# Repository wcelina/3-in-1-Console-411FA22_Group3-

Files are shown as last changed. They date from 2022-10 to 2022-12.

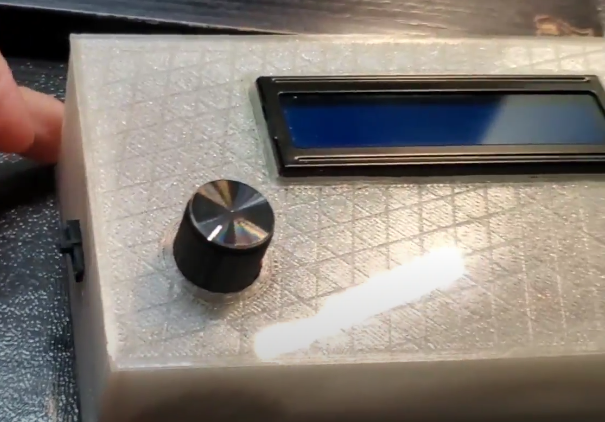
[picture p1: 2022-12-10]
product_design/411_other_sideview_photo.png

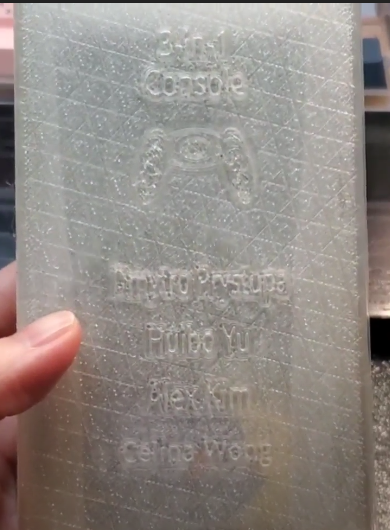
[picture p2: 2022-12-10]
product_design/411_backview_photo.png

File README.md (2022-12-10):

## 3-in-1 Console (Stopwatch, Counter, and Flappy Bird)
##### TLDR; On power up, the console should direct the user to the menu screen, where they can turn the knob to vary between the three modes and select the mode by clicking the rotary encoder. 

#
## Requirements:
##### Project management application - GanttProject 3.1.3
##### Circuit schematic design application - KiCad 6.0
##### Code software - Arduino IDE 2.0.3
##### 3D Design and Slicer - Tinkercad.com and Ultimaker Cura 5.2.1

#
## Recent Project Updates:

#### 12/8/22 - Presentation slides:
#### https://docs.google.com/presentation/d/1yn8I8TeqEF4ywxcgW0SFzS9HUh2eWH4x9auOoaWZxTw/edit?usp=sharing

#### 12/6/22 - All components and PCB are placed in a 3D printed compartment. Link of Flappy Bird demo:
#### https://drive.google.com/file/d/1Yfay8kJElGX3HygGRCzuhIqe8Dfigz_g/view?usp=sharing

#### 11/3/22 - The current breadboard prototype is wired with an LCD screen, push button, and power on/off switch. It successfully runs with a sample timer code. Due to complications and limitations of an LCD screen, we have placed an order for an OLED screen and will utilize that as soon as we receive it in about two business days (thank goodness for Amazon Prime). Link of demo below:
#### https://drive.google.com/drive/folders/1t0M0c-cClHCmyueLMgTcO8hawUu6y9SK

#
## Folder descriptions:

#### documents - Consists of weekly team documents and project information and specifications.

#### schematics - Consists of KiCad schematics and PCB layout, also available to view in PDF format.
##
### code:
##### rotarybutton - Testing program solely for the introduction of the rotary encoder and how it works
##### flappybird - Contains working Flappy Bird game
##### 411_combined_code - Contains menu option and selection from three modes: counter, stopwatch, and Flappy Bird

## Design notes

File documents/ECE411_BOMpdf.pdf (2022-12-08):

Bill Of Materials for: PRACTICUM GROUP THREE
Last modified: December 6th, 2022
PCB version: One
BOM revision: ONE | P/NP | = Place/Not Place (components marked NP are not stuffed on the board)
Cnt | Part References | P/NP Mfg | Mfg PN | Description | Dist | Dist Part Number | Cost Ea. | Cost Total
1 MP1 | P | Arduino | 1050-1024-ND | Arduino Uno REV3 [A000066] | Amazon | A000066 | $28.50 | $28.50
1 SW_SPST | P | E-Switch | EG1218 | 3 Pin Verticle Slide Switch | Digi-Key | EG1903-ND | $0.76 | $0.76
1 DISP | P | HiLetgo | 03-01-1498 | SPI Serial Interface Adapter 1602 LCD Display | Amazon | B07W5KC65S | $9.99 | $9.99
2 BS | NP | Duracell | 9V-MN1604 | Battery 9V Alkaline | Digi-Key | 3046-9V-MN1604-ND | $2.46 | $4.92
1 CLP | P | Keystone Electronics | 2242 | 9V Battery Clip Connector to Breadboard | Digi-Key | 36-2242-ND | $1.16 | $1.16
1 SW1 | P | Taiss | KY-040 | Rotary Encoder Module with Knob | Amazon | 673257216465 | $9.99 | $9.99
4 CLP | P | Keystone Electronics | 232 | BATT CONN SNAP 9V 1 CEL 4" LEADS | Digi-Key | 36-232-ND | $0.55 | $2.20
2 N/A | P | Preci-dip | 801-87-032-10-001101 | Dupoint header pins (straight) | Mouser | 437-8018703210001101 | $3.26 | $6.52
2 N/A | P | Preci-dip | 801-87-036-20-001101 | Dupoint header pins (90 degree) | Mouser | 437-8018703620001101 | $5.28 | $10.56
1 WIR | NP | ELEGOO | EL-CP-004 | Breadboard Wire Male-Male Male-Female Female-Female | Amazon | B01EV70C78 | $6.98 | $6.98
4 PCB | P | OSH Park | -- | PCB Boards | Oshpark | -- | $9.00 | $36.00
TOTAL: | $117.58

VERSION INFO
Rev | Date | Notes
1.Or1 2022-12-07 | Finalizing for presentation
1.Or0 2022-11-09 | Cleaned up parts, rough draft of board

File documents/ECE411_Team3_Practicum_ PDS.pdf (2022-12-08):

## Week 4: Product Design Specification (PDS)

Team 3: Celina Wong, Alex Kim, Huibo Yu, Dmytro Prystupa

Concept of Operations

Our project is a 3-in-1 counter, stopwatch, and gaming device. The counter will keep track of a number and increment as needed. The stopwatch will act as a timer and start/stop the clock as needed. There will be the ability to toggle through the menus/functions as well as reset the counter and stopwatch. We are also incorporating a game mode in our device for entertainment purposes and to add additional services to make our product more appealing to consumers.

The choice of our project was to develop a device that could be fun and practical to use. It can be used by consumers in various professions, is portable/pocket-sized, and is simple to use. The interests of our teammates involve gaming devices and jobs that require timed measurements, which ultimately lead us to the creation of this 3-in-1 Thingamabob.

This product can be utilized by everyone from any age range, although it might need to be kept away from toddlers due to the incorporation of some small components (such as buttons). The learning curve is also not that difficult - the user may need to refer back to the manual for instructions on how to switch between the three modes if they forget, but other than that, everything is pretty straightforward.

The main button’s functionality depends on the mode the user is on. For example, in the counter mode, clicking the button will increment the current number by one. In the stopwatch mode, the timer will start/stop a clock that starts at 0.00s. For both of these modes, holding the button for two seconds will reset the counter/timer. The gaming mode will present a classic Flappy Bird game, where pressing the button will make the bird jump. There are also two smaller buttons -one to power the device on/off, and the other to mute/unmute the device.

To switch between modes, the user will need to hold down the main button for three seconds to pop up the main menu. Clicking the button will alternate between the three modes, and holding down the button on the current selection for two seconds will allow the user to go into the selected mode.

Brief Market Analysis

We intend to market our device to customers that may utilize timing devices in their day-to-day life. For example, a flight attendant needs to count the number of passengers that board an airplane. With the help of our device, the flight attendant will be able to accurately count the number of passengers boarding the plane and kill some time with the gaming mode during their downtime. Some other professions involve classroom teachers, PE teachers, or sports-related trainers who use stopwatches/counters frequently.

The competition for basic counters and stopwatches is pretty high. There is also a close competitor: Team 11’s Handheld Video Game Console. However, the incorporation of our three modes along with a sleek, modern design, will give us an advantage that combines practicality and entertainment into one.

A generic counter/stopwatch goes for about $5 to $10 alone. Since we also have a game mode and more technology is involved, this could probably go for about at least $20 per unit.

In the future, with more investments, this device can also be upgraded to where the user can connect the device to a PC and install various firmware applications to add to their device so they can switch up the types of games to play on the device (ex. Crossy Road). Allowing the customer to install games will then enable us to increase the price of the product.

Requirements

- The user must be able to switch between the three modes
- The user must be able to select a mode
- The device must last for a full workday
- The battery must be able to be easily swapped out for a new one
- The device must turn on/off
- The screen should present color for the gaming mode
- The device should produce sounds for the gaming mode
- The user may increase/decrease the brightness of the screen
- The user may increase/decrease the volume
- The device may be rechargeable via micro-USB port

System Architecture

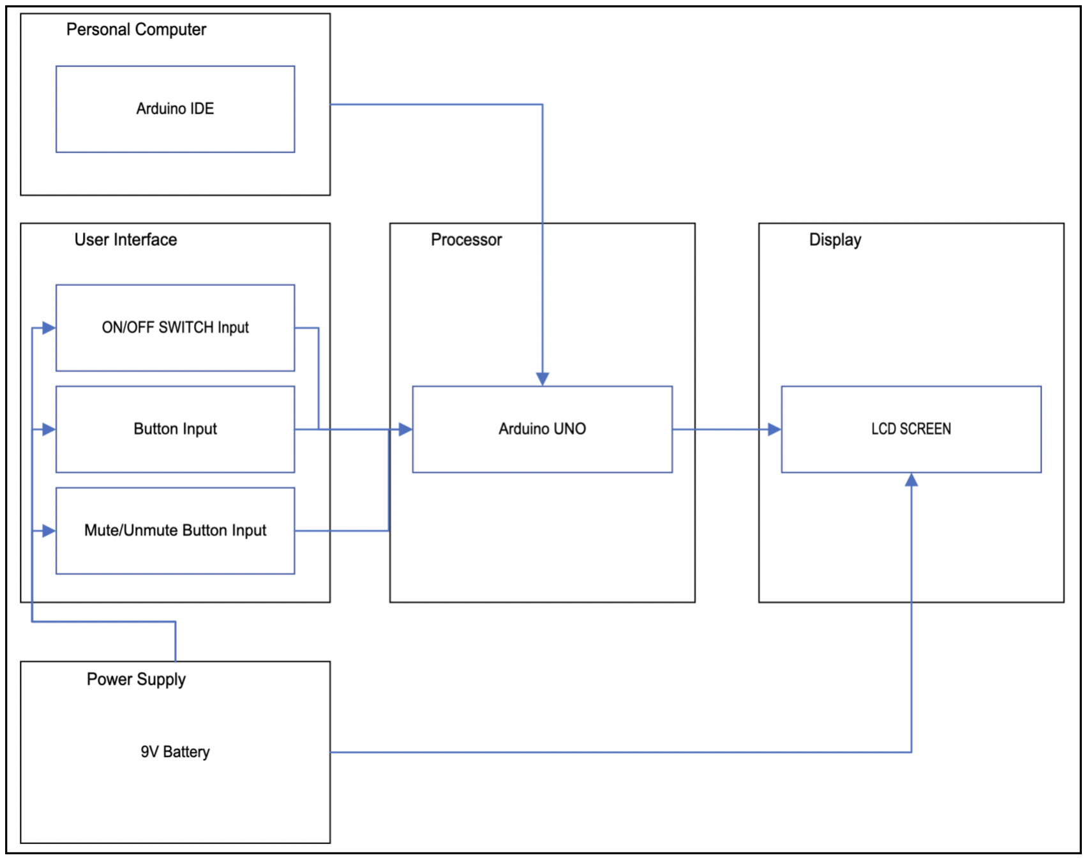
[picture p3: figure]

Figure 1.1. Initial level 1 block diagram.

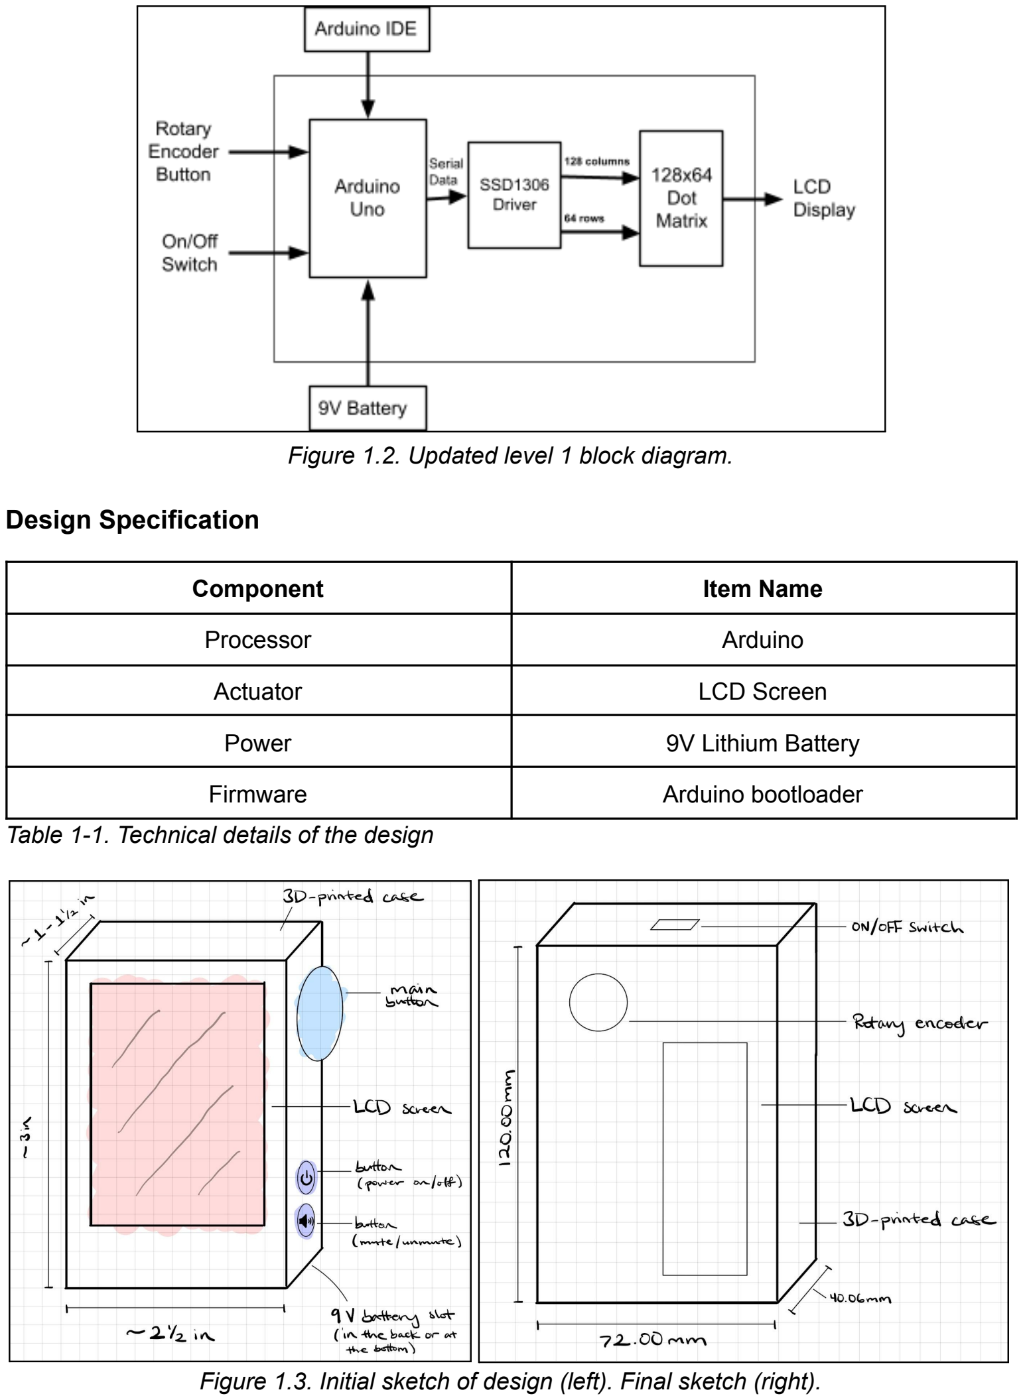
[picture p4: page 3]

Figure 1.2. Updated level 1 block diagram.

Design Specification

Component | Item Name
Processor | Arduino
Actuator | LCD Screen
Power | 9V Lithium Battery
Firmware | Arduino bootloader
Table 1-1. Technical details of the design

Figure 1.3. Initial sketch of design (left). Final sketch (right).

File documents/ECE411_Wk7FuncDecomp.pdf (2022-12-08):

## Week 7: Functional Decomposition

Team 3: Celina Wong, Alex Kim, Huibo Yu, Dmytro Prystupa

L0 Decomposition

Module | 3-in-1 Counter
Inputs | On/Off Switch Button: when pressed power on/off device Button: when pressed, the button will Run/Stop toggle signal 9V Power Supply
Outputs | LCD Screen
Functionality | Device is capable of acting as a counter, stopwatch, and a flappy bird game mode. It will be able to count the number of times the button is pushed and can be cleared to zero. The stopwatch counts the number of seconds after the button is pressed and will stop counting when pushed again (will be able to clear to zero also). Finally, our device will also have a flappy bird game mode for user entertainment.

(continued)

L1 Decomposition

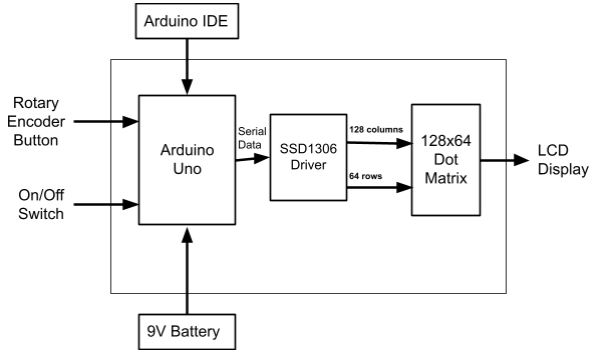
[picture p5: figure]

9V Battery: Level 1

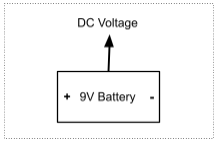
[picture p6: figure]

Module | 9V Battery
Inputs | N/A
Outputs | +/- 9V DC
Functionality | Delivers DC voltage to the Arduino Nano.

Arduino Nano: Level 1

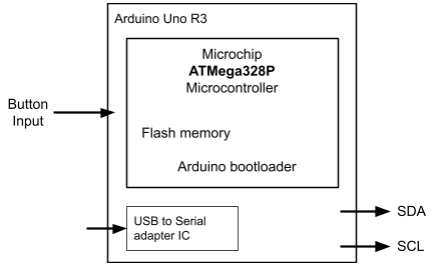
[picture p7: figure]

Module | Arduino Nano
Inputs | Main button, on/off switch
Outputs | Serial Data (SDA/SCL)
Functionality | PCBA (printed circuit board assembly) with ATMega328P microcontroller. It has a USB to serial-adapter along with a pre-loaded Arduino program.

SSD1306 Driver: Level 1

Module | SSD1306 Driver
Inputs | Serial Data (SDA/SCL)
Outputs | 128x64 Dot Matrix
Functionality | Display controller interfaces with microcontroller to get a visual output.

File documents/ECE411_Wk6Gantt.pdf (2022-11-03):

ECE411 Fall 2022 Project Gantt Chart | Nov 2, 2022 https://github.com/wcelina/411FA22_Group3/
Project manager | Alex Kim, Huibo Yu, Celina Wong, Dmytro Prystupa
Project dates | Oct 6, 2022 - Dec 9, 2022
Completion | 46%
Tasks | 15
Resources | 4

Name | Begin date | End date | Member
Research and Discussions | 10/6/22 | 10/10/22 | All
Project Selection | 10/11/22 | 10/12/22 | All
Project design specifications | 10/13/22 | 10/19/22 | All
Buy/order components | 10/20/22 | 10/26/22 | Dima
Preliminary schematic | 10/20/22 | 10/26/22 | Huibo
Breadboard Prototype | 10/27/22 | 11/2/22 | Alex
KiCad schematic | 10/27/22 | 11/2/22 | Huibo
CODE: Counter mode | 10/27/22 | 11/2/22 | Celina
CODE: Timer mode | 11/3/22 | 11/9/22 | Dima
Order PCB board | 11/3/22 | 11/9/22 | Alex
Assemble components | 11/10/22 | 11/16/22 | H & A
CODE: Game Mode | 11/10/22 | 11/16/22 | Celina
Debug and finalize code | 11/17/22 | 11/23/22 | D & C
ALL: Test and Debug Device | 11/24/22 | 11/30/22 | All
Presentation and Demo Prep | 12/2/22 | 12/8/22 | All
ECE411 Fall 2022 Project Gantt Chart | Nov 2, 2022
Tasks | 2

Name | Default role
Alex Kim | project manager
Huibo Yu | project manager
Celina Wong | project manager
Dmytro Prystupa | project manager

# Resources

3

# Gantt Chart

4

Name | Begin date | End date | Member
Research and Discussions | 10/6/22 | 10/10/22 | All
Project Selection | 10/11/22 | 10/12/22 | All
Project design specifications | 10/13/22 | 10/19/22 | All
Buy/order components | 10/20/22 | 10/26/22 | Dima
Preliminary schematic | 10/20/22 | 10/26/22 | Huibo
Breadboard Prototype | 10/27/22 | 11/2/22 | Alex
KiCad schematic | 10/27/22 | 11/2/22 | Huibo
CODE: Counter mode | 10/27/22 | 11/2/22 | Celina
CODE: Timer mode | 11/3/22 | 11/9/22 | Dima
Order PCB board | 11/3/22 | 11/9/22 | Alex
Assemble components | 11/10/22 | 11/16/22 | H & A
CODE: Game Mode | 11/10/22 | 11/16/22 | Celina
Debug and finalize code | 11/17/22 | 11/23/22 | D & C
ALL: Test and Debug Device | 11/24/22 | 11/30/22 | All
Presentation and Demo Prep | 12/2/22 | 12/8/22 | All
[ 5 Day(s) ] | Research and Discussions
[ 2 Day(s) ] | Project Selection
[ 7 Day(s) ] | Project design specifications
[ 7 Day(s) ] | Buy/order components
[ 7 Day(s) ] | Preliminary schematic
[ 7 Day(s) ] | Breadboard Prototype
[ 7 Day(s) ] | KiCad schematic
[ 7 Day(s) ] | CODE: Counter mode
[ 7 Day(s) ] | CODE: Timer mode
[ 7 Day(s) ] | Order PCB board
[ 7 Day(s) ] | Assemble components
[ 7 Day(s) ] | CODE: Game Mode
[ 7 Day(s) ] | Debug and finalize code
[ 7 Day(s) ] | ALL: Test and Debug Device
[ 7 Day(s) ] | Presentation and Demo Prep

2022

Week 40 | Week 41 | Week 42 | Week 43 | Week 44 | Week 45 | Week 46 | Week 47 | Week 48 | Week 49 | Week 50 | Week 51 | Week 52
9/25/22 | 10/2/22 | 10/9/22 | 10/16/22 | 10/23/22 | 10/30/22 | 11/6/22 | 11/13/22 | 11/20/22 | 11/27/22 | 12/4/22 | 12/11/22 | 12/18/22

# Resources Chart

5

Name | Default role
Alex Kim | project man...

Research and Discussions

Project Selection

Breadboard Prototype

Project design specificatio...

Order PCB board

Assemble components

ALL: Test and Debug Device

Presentation and Demo Pr...

Huibo Yu | project man...

Research and Discussions

Project Selection

Project design specificatio...

Preliminary schematic

KiCad schematic

Assemble components

ALL: Test and Debug Device

Presentation and Demo Pr...

Celina Wong | project man...

Research and Discussions

Project Selection

Project design specificatio...

KiCad schematic

CODE: Counter mode

CODE: Game Mode

Debug and finalize code

ALL: Test and Debug Device

Presentation and Demo Pr...

Dmytro Prystupa | project man...

Research and Discussions

Project Selection

Project design specificatio...

Buy/order components

Preliminary schematic

Breadboard Prototype

CODE: Timer mode

Debug and finalize code

ALL: Test and Debug Device

Presentation and Demo Pr...

200%

200%

Week 40 | Week 41 | Week 42 | Week 43 | Week 44 | Week 45 | Week 46 | Week 47 | Week 48 | Week 49 | Week 50 | Week 51 | Week 52
9/25/22 | 10/2/22 | 10/9/22 | 10/16/22 | 10/23/22 | 10/30/22 | 11/6/22 | 11/13/22 | 11/20/22 | 11/27/22 | 12/4/22 | 12/11/22 | 12/18/22

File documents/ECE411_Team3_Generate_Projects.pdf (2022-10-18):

## Week 3: Generate 3 Projects and Choose One

Team 3: Celina Wong, Alex Kim, Huibo Yu, Dmytro Prystupa

Project 1: Flappy Bird/Timer/Counter
This would be a device that switches between three different modes. One of the modes would allow the user to activate a timer until a button is pressed. The second mode would allow the user to use the same device as a counter. Every button click would automatically add one count and display it on a screen. The third of the three modes would allow the user to play a flappy bird game with the help of one button.
Sensor(s) | Controller(s) | Actuator(s)
- Push-button ● Switch | ● Arduino | ● LCD display

Brief explanation of why this idea was chosen:
I found a similar device online and thought it was a cool idea. I own a coffee stand and I use a timer and counter all of the time. At weddings, I use the counter to make sure that I serve and charge for the right amount of drinks. I also use a timer to time the grinding of the coffee beans. A lot of the time I just have time to kill while I wait for guests to order drinks, thus incorporating a game into the device would be a great idea.

Project 2: Automated Pill Dispenser
A portable, smart little box that reminds the user at a scheduled time to get a specific medication.
Sensor(s) | Controller(s) | Actuator(s)
- Infrared sensor ● Pressure sensor ● Temperature sensor ● Humidity sensor | ● Arduino | ● Speakers ● LCD display

Brief explanation of why this idea was chosen:
This could help people who don't have a good memory by reminding them to take their medication on time. Affordable and easy to carry.

Project 3: Speed Detector
The purpose of this project is to measure the speed of a motor & trigger the alarm if the speed exceeds a certain limit. The system can use a microcontroller with IR sensors to count the spin of a motor. The speed data can be displayed through the LCD screen and if the speed is over the limit then the system can alert a person through light/sound.
Sensor(s) | Controller(s) | Actuator(s)
- IR sensors (tachometer) | ● Arduino | ● Speakers ● LCD display ● LED bulb

Brief explanation of why this idea was chosen:
The system could monitor any motor that rotates and ensure it is running at a safe state. This can be implemented in many different practical applications depending on the design and industry/market we are trying to enter.

We are choosing…
Project 1: Flappy Bird/Timer/Counter

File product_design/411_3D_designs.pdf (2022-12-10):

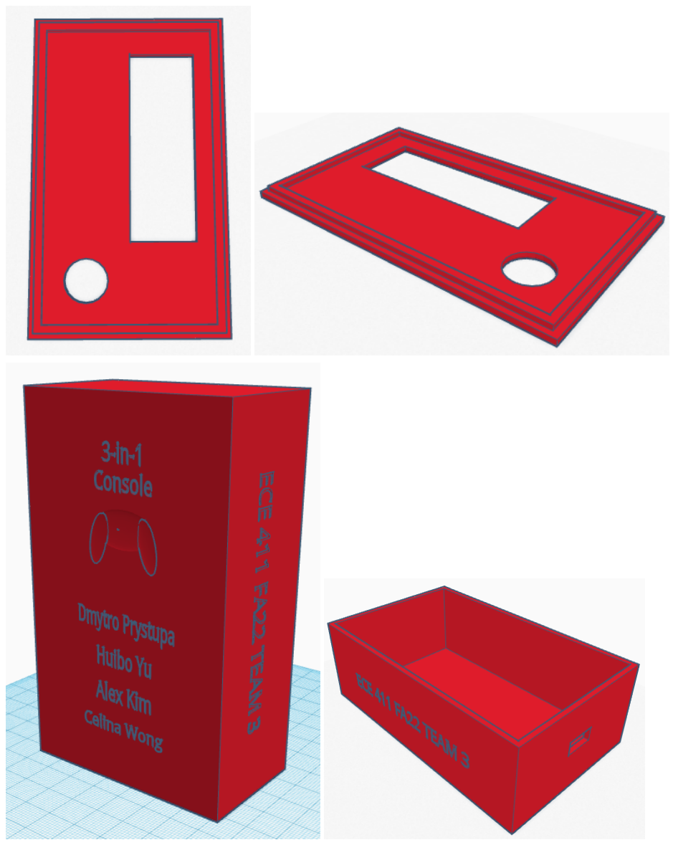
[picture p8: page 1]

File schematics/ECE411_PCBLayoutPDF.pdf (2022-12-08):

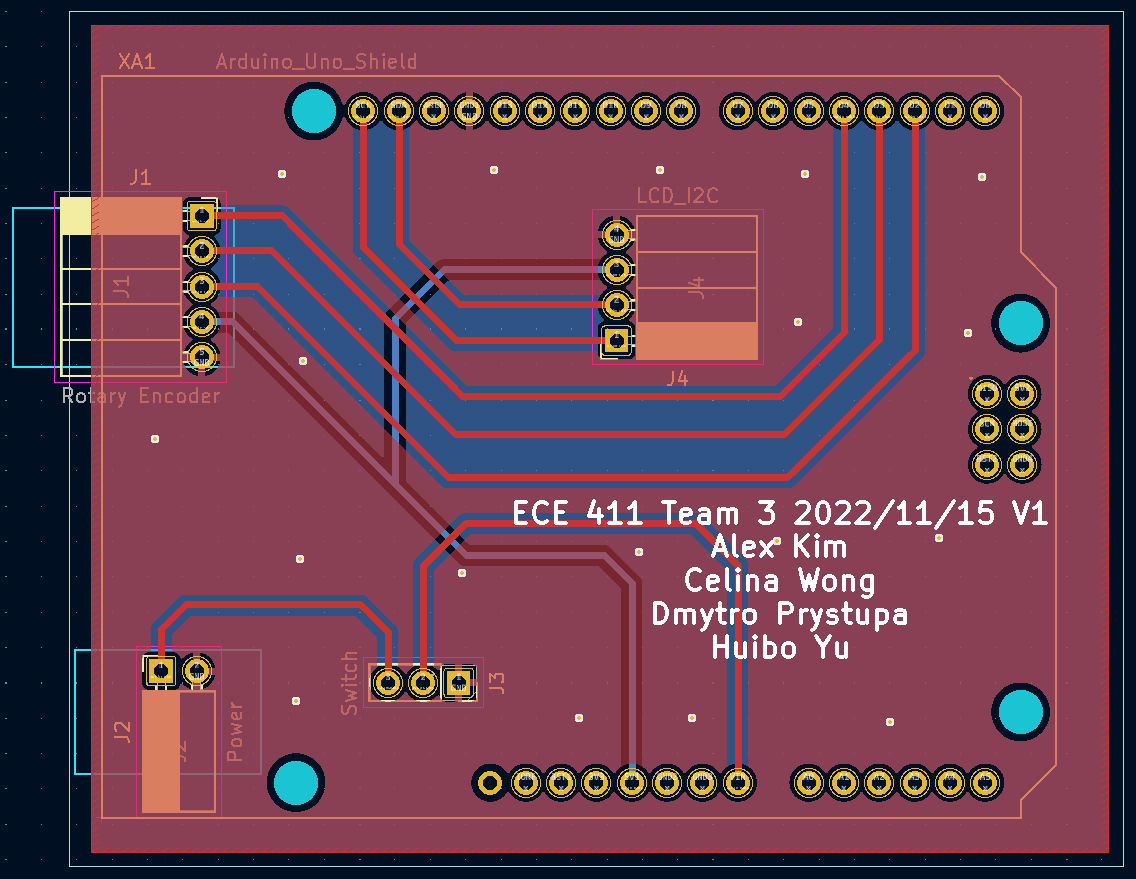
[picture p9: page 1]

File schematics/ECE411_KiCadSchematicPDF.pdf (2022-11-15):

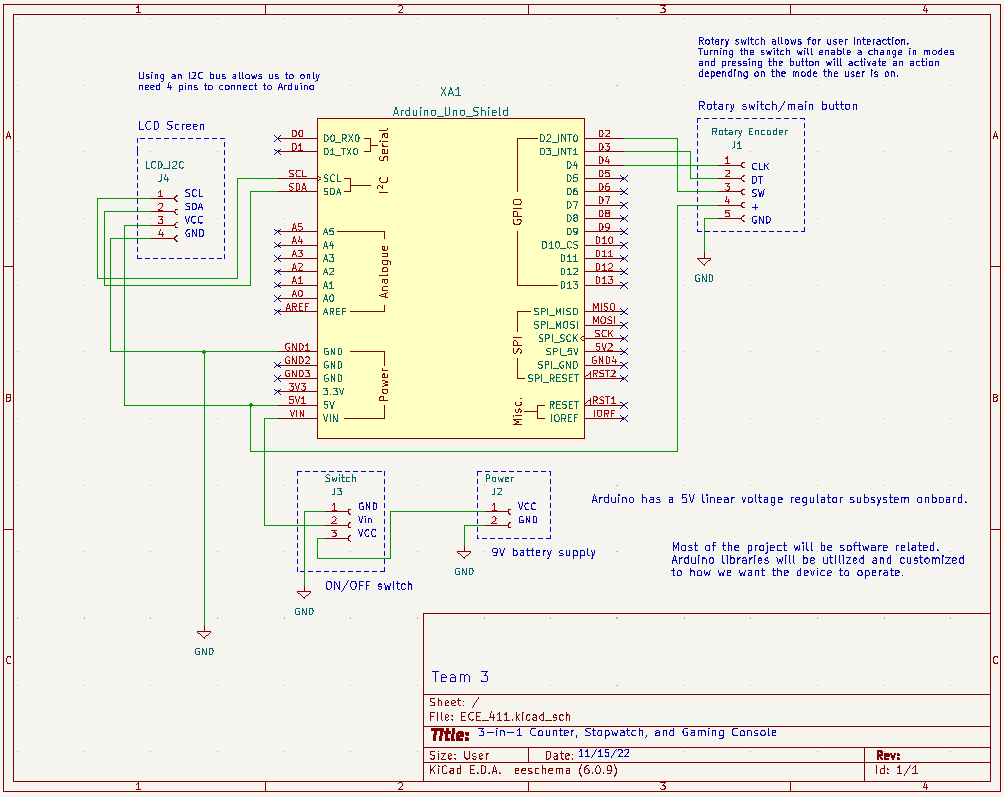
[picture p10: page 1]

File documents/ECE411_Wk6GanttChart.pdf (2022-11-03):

ECE411 GROUP 3 Gantt Chart

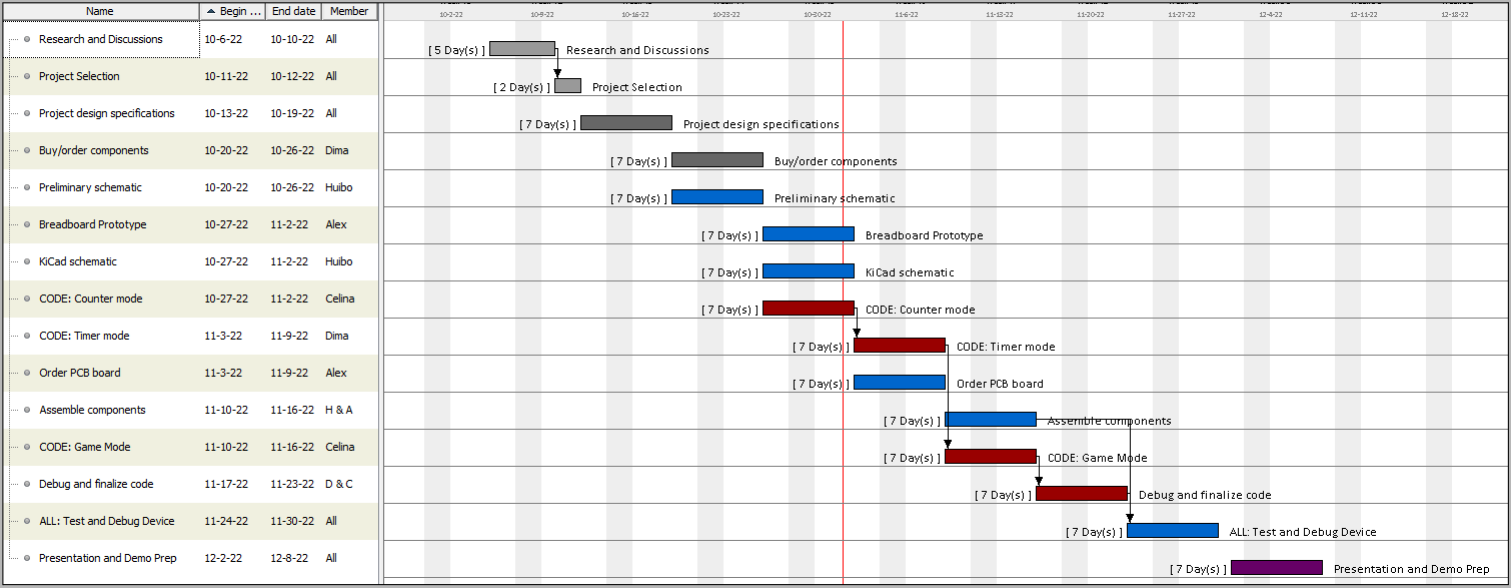
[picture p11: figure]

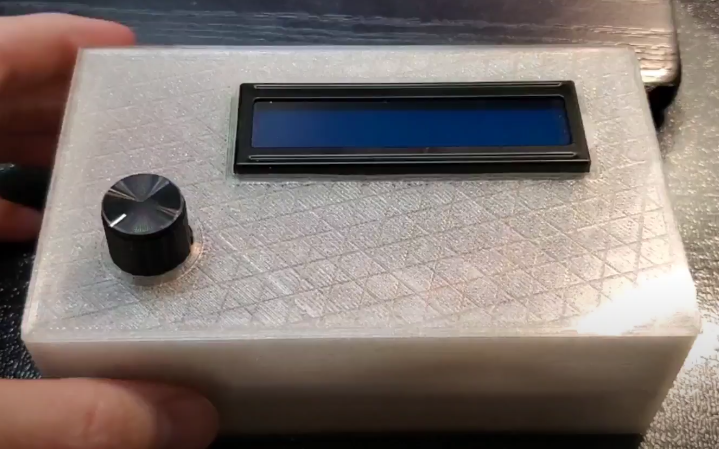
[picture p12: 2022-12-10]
product_design/411_basicview_photo.png

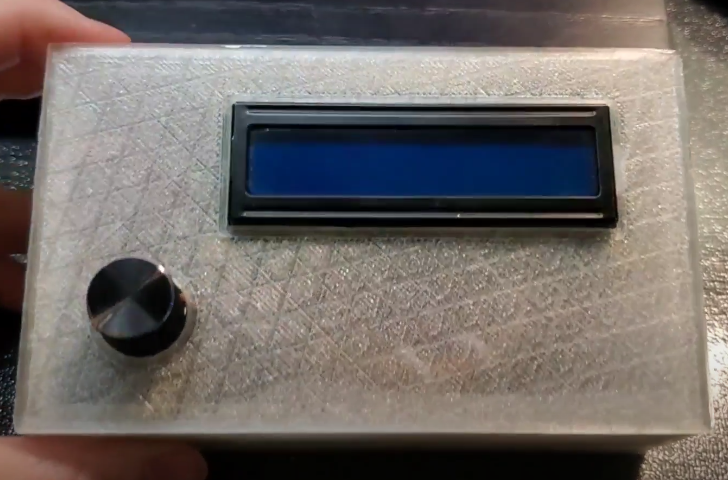
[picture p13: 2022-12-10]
product_design/411_topview_photo.png

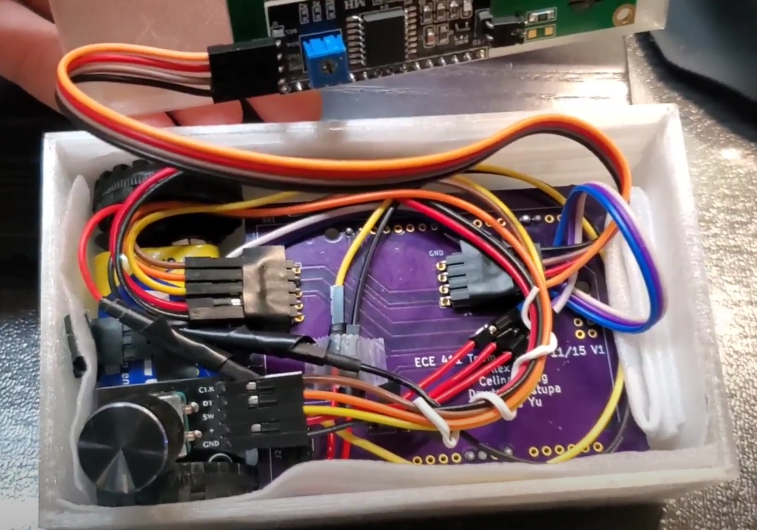
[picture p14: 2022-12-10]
product_design/411_insideview_photo.png

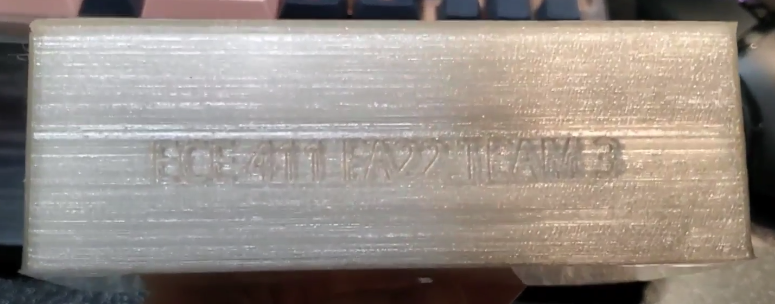
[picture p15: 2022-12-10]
product_design/411_sideview_photo.png

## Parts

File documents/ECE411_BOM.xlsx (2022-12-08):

Bill Of Materials for: PRACTICUM GROUP THREE
Last modified: December 6th, 2022
PCB version: One
BOM revision: ONE |  | P/NP | = Place/Not Place (components marked NP are not stuffed on the board)
Cnt | Part References | P/NP | Mfg | Mfg PN | Description | Dist | Dist Part Number | Cost Ea. | Cost Total
1 | MP1 | P | Arduino | 1050-1024-ND | Arduino Uno REV3 [A000066] | Amazon | A000066 | $28.50 | $28.50
1 | SW_SPST | P | E-Switch | EG1218 | 3 Pin Verticle Slide Switch | Digi-Key | EG1903-ND | $0.76 | $0.76
1 | DISP | P | HiLetgo | 03-01-1498 | SPI Serial Interface Adapter 1602 LCD Display | Amazon | B07W5KC65S | $9.99 | $9.99
2 | BS | NP | Duracell | 9V-MN1604 | Battery 9V Alkaline | Digi-Key | 3046-9V-MN1604-ND | $2.46 | $4.92
1 | CLP | P | Keystone Electronics | 2242 | 9V Battery Clip Connector to Breadboard | Digi-Key | 36-2242-ND | $1.16 | $1.16
1 | SW1 | P | Taiss | KY-040 | Rotary Encoder Module with Knob | Amazon | 673257216465 | $9.99 | $9.99
4 | CLP | P | Keystone Electronics | 232 | BATT CONN SNAP 9V 1 CEL 4" LEADS | Digi-Key | 36-232-ND | $0.55 | $2.20
2 | N/A | P | Preci-dip | 801-87-032-10-001101 | Dupoint header pins (straight) | Mouser | 437-8018703210001101 | $3.26 | $6.52
2 | N/A | P | Preci-dip | 801-87-036-20-001101 | Dupoint header pins (90 degree) | Mouser | 437-8018703620001101 | $5.28 | $10.56
1 | WIR | NP | ELEGOO | EL-CP-004 | Breadboard Wire Male-Male Male-Female Female-Female | Amazon | B01EV70C78 | $6.98 | $6.98
4 | PCB | P | OSH Park | -- | PCB Boards | Oshpark | -- | $9.00 | $36.00
 |  |  |  |  |  |  |  | TOTAL: | $117.58
VERSION INFO
Rev | Date | Notes
1.Or1 | 2022-12-07 | Finalizing for presentation
1.Or0 | 2022-11-09 | Cleaned up parts, rough draft of board
 |  |  |  |  | Arduino Uno:
 |  |  |  |  | https://www.amazon.com/Arduino-A000066-ARDUINO-UNO-R3/dp/B008GRTSV6
 |  |  |  |  | LCD:
 |  |  |  |  | https://www.amazon.com/HiLetgo-HD44780-I2C1602-Interface-Backlight/dp/B07W5KC65S
 |  |  |  |  | Rotary Encoder:
 |  |  |  |  | https://tinkersphere.com/buttons-switches/3045-rotary-encoder-module-with-knob.html
 |  |  |  |  | OR
 |  |  |  |  | https://www.amazon.com/Taiss-KY-040-Encoder-15%C3%9716-5-Arduino/dp/B07F26CT6B
 |  |  |  |  | ^this one has part number and model number, use whichever is easier ig
 |  |  |  |  | Battery clip connector:
 |  |  |  |  | https://www.digikey.com/en/products/detail/keystone-electronics/232/303804
 |  |  |  |  | ^assume we're getting like 4 of these
 |  |  |  |  | 90 degree Dupont header pins - male to female:
 |  |  |  |  | https://www.mouser.com/ProductDetail/Preci-dip/801-87-036-20-001101?qs=q5BRkYolQ3j1LJ%252BvAZHwNw%3D%3D
 |  |  |  |  | and the straight ones
 |  |  |  |  | https://www.mouser.com/ProductDetail/Preci-dip/801-87-032-10-001101?qs=FtMuP6KVi2RAkveJlUgcfA%3D%3D

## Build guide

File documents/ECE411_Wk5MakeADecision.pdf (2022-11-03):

## Week 5: Design Matrix & AHP Methodologies

Team 3: Celina Wong, Alex Kim, Huibo Yu, Dmytro Prystupa

Decision Matrix
Selecting an LCD Screen for our 3-in-1 stopwatch.

Identifying alternatives:

1. SunFounder IIC I2C 20x4 LCD Screen (Amazon.com: SunFounder LCD2004 Module with 3.3V Backlight Compatible with Arduino R3 Mega2560 Raspberry Pi Display of 20x4 White Characters on Blue Background. : Electronics) (https://www.amazon.com/SunFounder-Backlight-Raspberry-Characters-Background/dp/B01GPUMP9C?th=1)
2. SING F LTD 20x4 LCD (Amazon.com: SING F LTD Serial 2004 20x4 LCD Module Shield 5V Character LCD Module Display : Electronics) (https://www.amazon.com/SING-LTD-Serial-Compatible-Arduino/dp/B07MX6VVPW?hvadid=79852087642162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)
3. Nextion Basic Display (Amazon.com: Nextion Basic Display 2.8'' NX3224T028 2.8inch TFT Resistive Touch Screen Panel 320X240 UART HMI Intelligent LCD Display Module for Arduino Raspberry Pi ESP8266 : Electronics) (https://www.amazon.com/Nextion-Display-Module-NX3224T028-ESP8266/dp/B015DMP1VW?hvadid=80608001462485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)
Criteria | Weight scale wm (1-5) | SunFounder Display | SING F LTD Display | Nextion Display
Cost | 4 | 4 | 5 | 2
Compatibility | 5 | 5 | 4 | 5
Screen size | 5 | 5 | 4 | 3
Power Consumption | 2 | 1 | 1 | 1
Weight | 3 | 5 | 3 | 4
Total Score | | 83 | 71 | 62
Table 1.1. Decision Matrix table for an LCD Screen.

We can see from our decision matrix that the SunFounder display scored the highest at 83. In second place was the SING F LTD display with a score of 71. Finally, the Nextion display has a score of 62. From this, we can conclude that the SunFounder display is the winner and should be selected based on the criteria of our decision matrix. Of course, there are other factors that can be considered but these were the most important factors in selecting our display.

Analytical Hierarchy Process (AHP)
Selecting an LCD Screen for our 3-in-1 stopwatch.

1 Equal

3 “Moderately” more important

5 “Strongly” more important

7 “Very strongly” more important

9 “Extremely” more important Table 2.1. Pair-wise comparison of each criterion for relative importance.

| Cost | Compatibility | Screen Size | Power Consumption | Screen Weight | Mean | Weight
Cost | 1 | 1/3 | 3 | 5 | 7 | 2 | 0.28
Compatibility | 3 | 1 | 5 | 3 | 9 | 3.3 | 0.46
Screen Size | 1/3 | 1/5 | 1 | 3 | 3 | 0.9 | 0.14
Power Consumption | 1/5 | 1/3 | 1/3 | 1 | 5 | 0.6 | 0.08
Screen Weight | 1/7 | 1/9 | 1/3 | 1/5 | 1 | 0.3 | 0.04

Table 2.2. Determining criteria weightings and calculations.

| Cost | α | Cost Rating
SunFounder | $10.99 | 0.67 | 0.35
SING F LTD | $7.39 | 1.0 | 0.53
Nextion | $32.99 | 0.22 | 0.12
Table 2.3. Cost rating between brands.
| Star Rating | α | Compatibility Rating
SunFounder | 5 | 1 | 0.48
SING F LTD | 3.5 | 0.7 | 0.33
Nextion | 2 | 0.4 | 0.19
Table 2.4. Compatibility rating between brands.
| SunFounder | SING F LTD | Nextion | Screen Size Rating
SunFounder | 1 | 1/3 | 5 | 0.39
SING F LTD | 3 | 1 | 1/4 | 0.30
Nextion | 1/5 | 4 | 1 | 0.31
Table 2.5. Screen size rating between brands.
| SunFounder | SING F LTD | Nextion | Power Consumption Rating
SunFounder | 1 | 1 | 1 | 0.33
SING F LTD | 1 | 1 | 1 | 0.33
Nextion | 1 | 1 | 1 | 0.33
Table 2.6. Power consumption rating between brands. The working voltage for all three brands are identical (working voltage = 5V).

| SunFounder | SING F LTD | Nextion | mean | Screen Weight Rating
SunFounder | 1 | 3 | 5 | 2.5 | 0.64
SING F LTD | 1/3 | 1 | 3 | 1 | 0.26
Nextion | 1/5 | 1/3 | 1 | 0.4 | 0.1
Table 2.7 Screen weight rating between brands
| SunFounder | SING F LTD | Nextion
Cost | 0.28 | 0.35 | 0.53 | 0.12
Compatibility | 0.46 | 0.48 | 0.33 | 0.19
Screen Size | 0.14 | 0.39 | 0.30 | 0.31
Power Consumption | 0.08 | 0.33 | 0.33 | 0.33
Screen Weight | 0.04 | 0.64 | 0.26 | 0.10
Score | | 0.44 | 0.30 | 0.21
Table 2.8. Final AHP table.

We can see from our Analytical Hierarchy Process (AHP) that the SunFounder scored the highest. The SING F LTF display placed second, and the Nextion display placed third. This matches our final result from our Decision Matrix. Before we began our AHP analysis, we had assumed our final result would match our Decision Matrix done before. This process helped us make a decision on which display to use for our project.

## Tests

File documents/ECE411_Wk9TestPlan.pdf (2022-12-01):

# FA22 ECE 411 Team 3: Test Plan

### 3-in-1 Stopwatch, Counter, and Flappy Bird

Celina Wong | Alex Kim | Dmytro Prystupa | Huibo Yu

Test Author: Alex Kim & Huibo Yu
Test Case Name: | Portable 3-in-1 Stopwatch power up #1 | Test ID #: | Stopwatch power up-T-01
Description: | Checks that our system powers up with no issues and is safe (smoke test). To do this, we will gradually introduce power to our system instead of starting off with full power. Once the PCB board is power tested and verified, we can introduce the full power needed for our system. | Type: | ☑ white box □ black box □ ________

Tester Information

| Name of Tester: | Alex Kim & Huibo Yu | Date: | 11/29/2022
| HW/SW Version: | 1.0 | Time: | 9:07AM
| Setup: | Test stopwatch power system using an external power supply & Multimeter to ensure our system is safe and fully functional.
S T E P | Action | Expected Result | P A S S | F A I L | N / A | Comments
1 | Ensure all wires are connected properly. | There should be no loose wires or connections in our system. | | | ✔ | Have not built the device with the PCB yet.
2 | Gradually power up using an external power supply. | By using an external power supply, we can control the amount of power our system is getting before reaching full, peak power. | | | ✔ | These will all be tested by 12/4.
3 | Verify & check that each component is getting power. | Use a Multimeter to check that each component is getting power/current to it. | | | ✔
4 | Turning on the switch turns on the LCD screen. | The Arduino UNO R3 indicator light should light up normally when the switch is on, and the LCD screen should light up normally. | | | ✔
5 | Rotary encoder button functionality. | Use an external power source to measure the minimum power that can make the rotary encoder work. It should be less than the power of the power source we are equipped with. | | | ✔
5 | Introduce our 9V battery as a power supply. | After checking that our system is fully functional thus far, we will hook up our battery power supply to the system and verify our stopwatch is functioning properly. | | | ✔
| Overall test result:

Test Author: Dmytro Prystupa & Celina Wong
Test Case Name: | Portable 3-in-1 Stopwatch code test/verification #1 | Test ID #: | Stopwatch code check-T- 01
Description: | This test case makes sure the firmware is operating properly. On power up, there should be a main menu for the user to select between three modes, and selecting a mode will enable the user to go into that feature. Each mode should operate accordingly. | Type: | ☑ white box □ black box □ ________

Tester Information

| Name of Tester: | Dmytro Prystupa & Celina Wong | Date: | 11/30/2022
| HW/SW Version: | 1.0 | Time: | 10:19PM
| Setup: | Write code on PC and flash to Arduino board.
S T E P | Action | Expected Result | P A S S | F A I L | N / A | Comments
1 | Main menu | This screen shows three options for the user select from. Selecting an option will go to that function. Alternatively, the user should be able to go from a function and back to the main menu. | | | ✔ | Have not tested yet.
2 | Timer mode | This mode should start at 0. A button click should start the timer and include the format of MM:SS.ZZ (minutes, seconds, and milliseconds). Return to main menu if button is held down for two seconds. | ✔ | | | This functionality operates accordingly by itself.
3 | Counter mode | This mode should start at count of 0. Each button click will increment the current count by 1. Return to main menu if button is held down for two seconds. | ✔ | | | This functionality operates accordingly by itself.
4 | Flappy Bird mode | This mode prompt the user to press the button. After a button press, there will be an animated character that stays at the same spot, and blocks of random sizes will inch closer to the character. If the character hits the blocks, then the game will end. If the character successfully jumps over a block, the small counter at the top right of the screen will increment by 1. The user can allow the character to jump by pressing the button. Return to main menu if button is held down for two seconds. | ✔ | | | This functionality operates accordingly by itself.
| Overall test result:

Test Author: Dmytro Prystupa & Celina Wong
Test Case Name: | Portable 3-in-1 Stopwatch button functionality check #1 | Test ID #: | Stopwatch button-T-01
Description: | What is this test case testing? Which requirements, which specifications, etc. This test case makes sure the rotary button performs properly. Rotating & holding the knob will allow the user to navigate through the system accordingly. | Type: | ☑ white box □ black box □ ________

Tester Information
| Name of Tester: | Dmytro Prystupa & Celina Wong | Date: | 11/30/2022
| HW/SW Version: | 1.0 | Time: | 10:36PM
| Setup: | Wire the Rotary Encoder into the Arduino.
S T E P | Action | Expected Result | P A S S | F A I L | N / A | Comments
1 | Button Press | When pressing the button down the user makes one selection. | ✔ | | | This function operates normally.
2 | Button Short Press | When the button is pressed swiftly after the user has made the function selection the function will start. A short press will result in the start of the timer, in timer mode. A short press will result in a character jump, in game mode. A short press will add one to the counter, in count mode. | ✔ | | | This function operates normally.
3 | Button Long Press | Holding the button down for four seconds will return the user back to the main menu. | | | ✔
4 | Button Scroll Counter Clockwise | Button Scroll counter clockwise should highlight an option above the option that is currently highlighted. | ✔ | | | This function operates normally.
5 | Button Scroll Clockwise | Button scroll clockwise should highlight an option below the option that is currently highlighted. | ✔ | | | This function operates normally.
| Overall test result:

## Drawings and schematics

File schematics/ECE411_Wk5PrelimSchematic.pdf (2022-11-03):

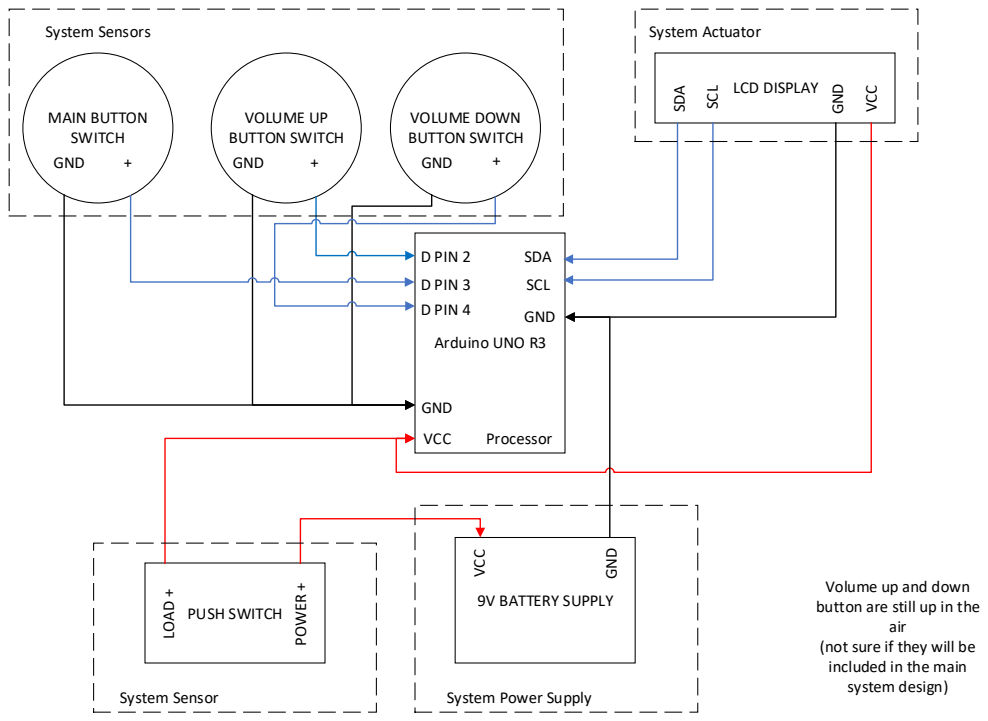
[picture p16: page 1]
Arduino UNO R3; VCC; GND; LCD DISPLAY; SDA; SCL; VOLUME UP BUTTON SWITCH; D PIN 2; PUSH SWITCH; 9V BATTERY SUPPLY; POWER +; LOAD +; VOLUME DOWN BUTTON SWITCH; MAIN BUTTON SWITCH; D PIN 3; D PIN 4; System Actuator; System Sensor; System Power Supply; System Sensors; Processor; air

Volume up and down
button are still up in the

(not sure if they will be
included in the main
system design)

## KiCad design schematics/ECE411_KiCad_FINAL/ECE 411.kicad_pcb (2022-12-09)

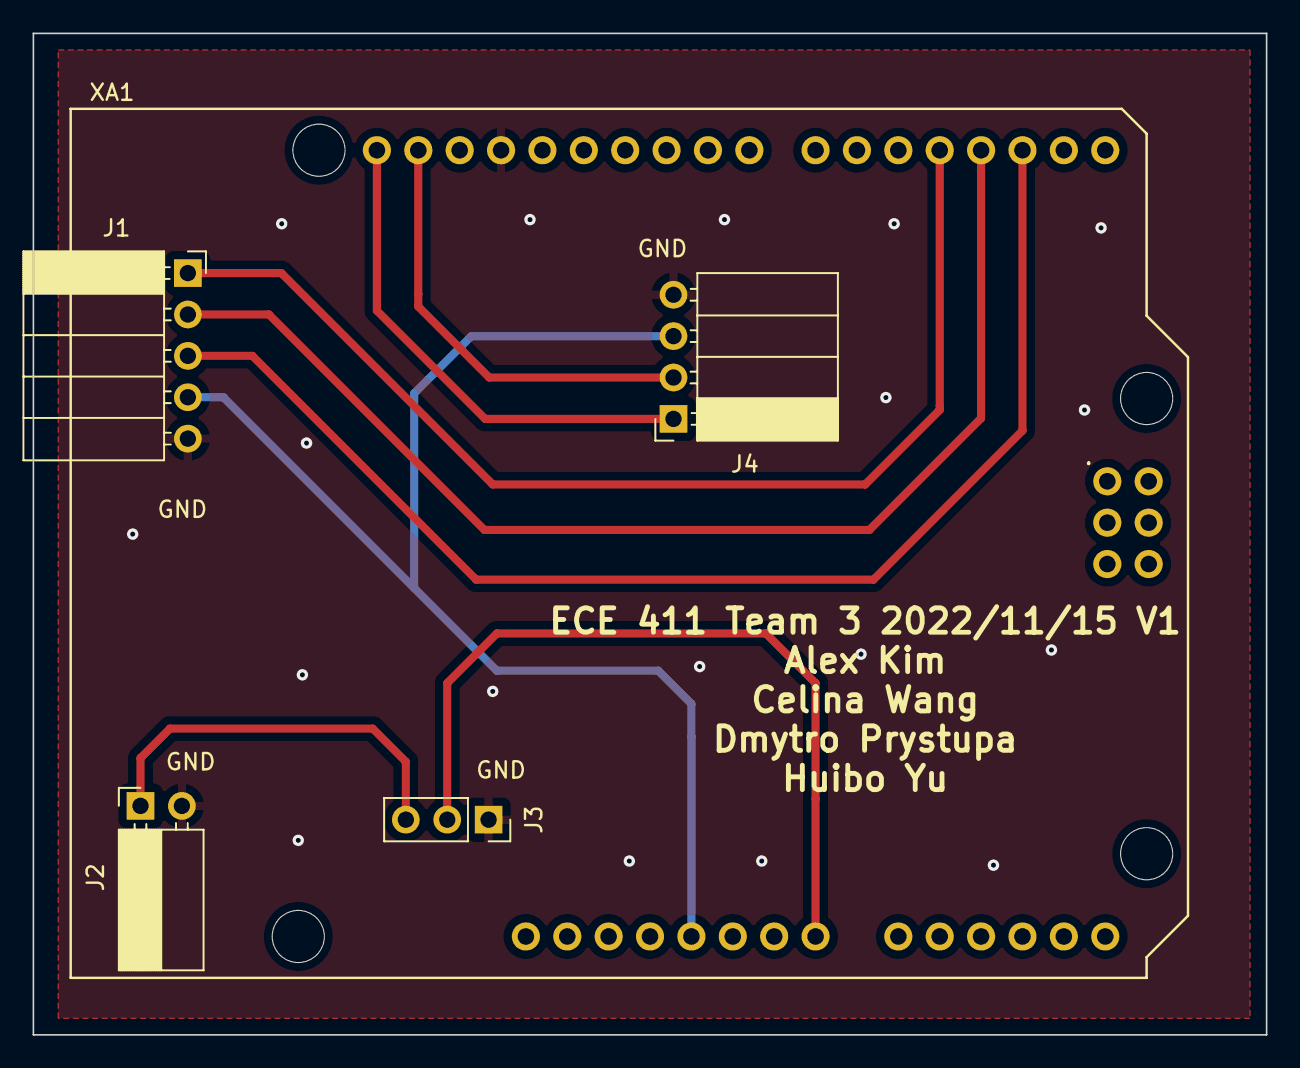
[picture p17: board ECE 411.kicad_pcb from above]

Board: 2 copper layers, 75.7 x 61.5 mm, 5 parts (0 on the bottom side), 9 nets.

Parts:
J1: Rotary Encoder; PinSocket_1x05_P2.54mm_Horizontal
J2: Power; PinSocket_1x02_P2.54mm_Horizontal
J3: Switch; PinSocket_1x03_P2.54mm_Vertical
J4: LCD_I2C; PinSocket_1x04_P2.54mm_Horizontal
XA1: Arduino_Uno_Shield

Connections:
GND: J1.5, J2.2, J3.1, J4.4, XA1.GND1 (GND)
unnamed: J1.1, XA1.D4
unnamed: J1.2, XA1.D3 (D3_INT1)
unnamed: J1.3, XA1.D2 (D2_INT0)
unnamed: J1.4, J4.3, XA1.5V1 (5V)
unnamed: J2.1, J3.3
unnamed: J3.2, XA1.VIN
unnamed: J4.1, XA1.SCL
unnamed: J4.2, XA1.SDA

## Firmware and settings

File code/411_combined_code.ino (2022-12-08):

#include <Wire.h> 
#include <LiquidCrystal_I2C.h>
#define clk 2
#define dt  3
#define btn 4
#define led 10
#define PIN_AUTOPLAY 1
#define PIN_READWRITE 10
#define PIN_CONTRAST 12

#define SPRITE_RUN1 1
#define SPRITE_RUN2 2
#define SPRITE_JUMP 3
#define SPRITE_JUMP_UPPER '.'         // Use the '.' character for the head
#define SPRITE_JUMP_LOWER 4
#define SPRITE_TERRAIN_EMPTY ' '      // User the ' ' character
#define SPRITE_TERRAIN_SOLID 5
#define SPRITE_TERRAIN_SOLID_RIGHT 6
#define SPRITE_TERRAIN_SOLID_LEFT 7

#define HERO_HORIZONTAL_POSITION 1    // Horizontal position of hero on screen

#define TERRAIN_WIDTH 16
#define TERRAIN_EMPTY 0
#define TERRAIN_LOWER_BLOCK 1
#define TERRAIN_UPPER_BLOCK 2

#define HERO_POSITION_OFF 0          // Hero is invisible
#define HERO_POSITION_RUN_LOWER_1 1  // Hero is running on lower row (pose 1)
#define HERO_POSITION_RUN_LOWER_2 2  //                              (pose 2)

#define HERO_POSITION_JUMP_1 3       // Starting a jump
#define HERO_POSITION_JUMP_2 4       // Half-way up
#define HERO_POSITION_JUMP_3 5       // Jump is on upper row
#define HERO_POSITION_JUMP_4 6       // Jump is on upper row
#define HERO_POSITION_JUMP_5 7       // Jump is on upper row
#define HERO_POSITION_JUMP_6 8       // Jump is on upper row
#define HERO_POSITION_JUMP_7 9       // Half-way down
#define HERO_POSITION_JUMP_8 10      // About to land

#define HERO_POSITION_RUN_UPPER_1 11 // Hero is running on upper row (pose 1)
#define HERO_POSITION_RUN_UPPER_2 12 //                              (pose 2)
static char terrainUpper[TERRAIN_WIDTH + 1];
static char terrainLower[TERRAIN_WIDTH + 1];
static bool buttonPushed = false;

LiquidCrystal_I2C lcd(0x27, 16, 2);

String options[] = {"Game", "Counter", "Stop Watch"};
int max_options = sizeof(options)/sizeof(options[0]);
int state_clk_old;
int state_btn_old;
int count = 0;
bool hz_1 = false;
bool mono = false;
unsigned long encoder1 = 0;
unsigned long encoder2 = 0;
int etatBouton,cp,test;
int a = 0;
int e = 7; 

void setup() {
  Serial.begin(9600);
  lcd.init();
  lcd.backlight();
  pinMode(led, OUTPUT);
  pinMode(clk, INPUT);
  pinMode(dt, INPUT);
  pinMode(btn, INPUT_PULLUP);
  state_clk_old = digitalRead(clk);
  state_btn_old = digitalRead(btn);
  show_menu();
  pinMode(PIN_READWRITE, OUTPUT);
  digitalWrite(PIN_READWRITE, LOW);
  pinMode(PIN_CONTRAST, OUTPUT);
  digitalWrite(PIN_CONTRAST, LOW);
  pinMode(btn, INPUT);
  digitalWrite(btn, HIGH);
  pinMode(PIN_AUTOPLAY, OUTPUT);
  digitalWrite(PIN_AUTOPLAY, HIGH);

  // Digital pin 2 maps to interrupt 0
  attachInterrupt(0/*PIN_BUTTON*/, buttonPush, FALLING);

  initializeGraphics();

  lcd.begin(16, 2);
  pinMode(e,INPUT);
  
  
}

void loop() {
  int state_btn = digitalRead(btn);

  encoder();
  if(state_btn_old == HIGH && state_btn == LOW){
    run_option();
  }

  if(millis() >= encoder1 + 500){
    encoder1 = millis();
    if(hz_1) digitalWrite(led, !digitalRead(led));
  }

  if(millis() >= encoder2 + 6000){
    if(mono) digitalWrite(led, LOW);
  }

  state_btn_old = state_btn;
}


void run_option(){
  if(count == 0){
    lcd.clear();
    lcd.print("Game");
    game_mode();
  }
  if(count == 1){
    lcd.clear();
    lcd.setCursor(5,0);
    lcd.print("Count#");
    counter_mode();
  }
  if(count == 2){
    lcd.clear();
    lcd.setCursor(0,0);
    lcd.print("Seconds:");
    stopwatch_mode();
  }
  if(count == 3){
    encoder2 = millis();
    mono = true;
  }else{
    mono = false;
  }
}


void encoder(){
  int state_clk = digitalRead(clk);
  int state_dt = digitalRead(dt);
  
  if(state_clk_old == HIGH && state_clk == LOW){
    if(state_dt == LOW){
      count--;
      a=0;
    }else{
      count++;
      a=0;
    }
    if(count < 0) count = max_options - 1;
    if(count > max_options-1) count = 0;
    
    show_menu();
  }

  delay(5);
  state_clk_old = state_clk;
}

void show_menu(){
  lcd.clear();
  lcd.setCursor(0,0);
  lcd.print("Menu:");
  lcd.setCursor(0,1);
  lcd.print(options[count]);
}


void stopwatch_mode(){
lcd.backlight();

etatBouton = digitalRead(btn);
if (etatBouton == 0) //if the button is pressed
{ test=1;
cp=0; // initialize the timer to 0
while(test==1) {
lcd.setCursor(11, 0);
cp++; // increment the counter
lcd.print(cp);
lcd.setCursor(0,0);
delay(1000);
etatBouton = digitalRead(btn);
if (etatBouton == 0) { //if the button is pressed a second time
test=0; // stop the clock
etatBouton = digitalRead(btn);
delay(1000);
}
}
}
}

void counter_mode(){
  int button = digitalRead(btn);
  
  
   lcd.setCursor(7, 1);
    lcd.print(a);
  
  
  if (button == 0) {
    a ++;
    lcd.setCursor(7, 1);
    lcd.print(a);
     delay(200);
    }

}


void game_mode(){static byte heroPos = HERO_POSITION_RUN_LOWER_1;
  static byte newTerrainType = TERRAIN_EMPTY;
  static byte newTerrainDuration = 1;
  static bool playing = false;
  static bool blink = false;
  static unsigned int distance = 0;

  if (!playing) {
    drawHero((blink) ? HERO_POSITION_OFF : heroPos, terrainUpper, terrainLower, distance >> 3);
    if (blink) {
      lcd.setCursor(0, 0);
      lcd.print("FlappyBird");
    }
    delay(250);
    blink = !blink;
    if (buttonPushed) {
      initializeGraphics();
      heroPos = HERO_POSITION_RUN_LOWER_1;
      playing = true;
      buttonPushed = false;
      distance = 0;
    }
    return;
  }

  // Shift the terrain to the left
  advanceTerrain(terrainLower, newTerrainType == TERRAIN_LOWER_BLOCK ? SPRITE_TERRAIN_SOLID : SPRITE_TERRAIN_EMPTY);
  advanceTerrain(terrainUpper, newTerrainType == TERRAIN_UPPER_BLOCK ? SPRITE_TERRAIN_SOLID : SPRITE_TERRAIN_EMPTY);

  // Make new terrain to enter on the right
  if (--newTerrainDuration == 0) {
    if (newTerrainType == TERRAIN_EMPTY) {
      newTerrainType = (random(3) == 0) ? TERRAIN_UPPER_BLOCK : TERRAIN_LOWER_BLOCK;
      newTerrainDuration = 2 + random(10);
    } else {
      newTerrainType = TERRAIN_EMPTY;
      newTerrainDuration = 10 + random(10);
    }
  }

  if (buttonPushed) {
    if (heroPos <= HERO_POSITION_RUN_LOWER_2) heroPos = HERO_POSITION_JUMP_1;
    buttonPushed = false;
  }

  if (drawHero(heroPos, terrainUpper, terrainLower, distance >> 3)) {
    playing = false; // The hero collided with something. Too bad.
  } else {
    if (heroPos == HERO_POSITION_RUN_LOWER_2 || heroPos == HERO_POSITION_JUMP_8) {
      heroPos = HERO_POSITION_RUN_LOWER_1;
    } else if ((heroPos >= HERO_POSITION_JUMP_3 && heroPos <= HERO_POSITION_JUMP_5) && terrainLower[HERO_HORIZONTAL_POSITION] != SPRITE_TERRAIN_EMPTY) {
      heroPos = HERO_POSITION_RUN_UPPER_1;
    } else if (heroPos >= HERO_POSITION_RUN_UPPER_1 && terrainLower[HERO_HORIZONTAL_POSITION] == SPRITE_TERRAIN_EMPTY) {
      heroPos = HERO_POSITION_JUMP_5;
    } else if (heroPos == HERO_POSITION_RUN_UPPER_2) {
      heroPos = HERO_POSITION_RUN_UPPER_1;
    } else {
      ++heroPos;
    }
    ++distance;

    digitalWrite(PIN_AUTOPLAY, terrainLower[HERO_HORIZONTAL_POSITION + 2] == SPRITE_TERRAIN_EMPTY ? HIGH : LOW);
  }
  delay(85);
}



void initializeGraphics() {
  static byte graphics[] = {
    // Run position 1
  
    B00000,
    B01110,
    B01101,
    B00110,
    B11110,
    B01110,
    B10010,
    B00000,

    // Run position 2
    B00000,
    B01110,
    B01101,
    B00110,
    B11110,
    B01110,
    B01100,
    B00000,


    // Jump
    B00000,
    B01110,
    B01101,
    B11110,
    B00010,
    B01110,
    B00000,
    B00000,
    
    // Jump lower
    B01110,
    B00000,
    B00000,
    B10000,
    B00000,
    B00000,
    B00000,
    B00000,
    // Ground
    B11111,
    B11111,
    B11111,
    B11111,
    B11111,
    B11111,
    B11111,
    B11111,
    // Ground right
    B00011,
    B00011,
    B00011,
    B00011,
    B00011,
    B00011,
    B00011,
    B00011,
    // Ground left
    B11000,
    B11000,
    B11000,
    B11000,
    B11000,
    B11000,
    B11000,
    B11000,
  };
  int i;
  // Skip using character 0, this allows lcd.print() to be used to
  // quickly draw multiple characters
  for (i = 0; i < 7; ++i) {
    lcd.createChar(i + 1, &graphics[i * 8]);
  }
  for (i = 0; i < TERRAIN_WIDTH; ++i) {
    terrainUpper[i] = SPRITE_TERRAIN_EMPTY;
    terrainLower[i] = SPRITE_TERRAIN_EMPTY;
  }
}

// Slide the terrain to the left in half-character increments


void advanceTerrain(char* terrain, byte newTerrain) {
  for (int i = 0; i < TERRAIN_WIDTH; ++i) {
    char current = terrain[i];
    char next = (i == TERRAIN_WIDTH - 1) ? newTerrain : terrain[i + 1];
    switch (current) {
      case SPRITE_TERRAIN_EMPTY:
        terrain[i] = (next == SPRITE_TERRAIN_SOLID) ? SPRITE_TERRAIN_SOLID_RIGHT : SPRITE_TERRAIN_EMPTY;
        break;
      case SPRITE_TERRAIN_SOLID:
        terrain[i] = (next == SPRITE_TERRAIN_EMPTY) ? SPRITE_TERRAIN_SOLID_LEFT : SPRITE_TERRAIN_SOLID;
        break;
      case SPRITE_TERRAIN_SOLID_RIGHT:
        terrain[i] = SPRITE_TERRAIN_SOLID;
        break;
      case SPRITE_TERRAIN_SOLID_LEFT:
        terrain[i] = SPRITE_TERRAIN_EMPTY;
        break;
    }
  }
}

bool drawHero(byte position, char* terrainUpper, char* terrainLower, unsigned int score) {
  bool collide = false;
  char upperSave = terrainUpper[HERO_HORIZONTAL_POSITION];
  char lowerSave = terrainLower[HERO_HORIZONTAL_POSITION];
  byte upper, lower;
  switch (position) {
    case HERO_POSITION_OFF:
      upper = lower = SPRITE_TERRAIN_EMPTY;
      break;
    case HERO_POSITION_RUN_LOWER_1:
      upper = SPRITE_TERRAIN_EMPTY;
      lower = SPRITE_RUN1;
      break;
    case HERO_POSITION_RUN_LOWER_2:
      upper = SPRITE_TERRAIN_EMPTY;
      lower = SPRITE_RUN2;
      break;
    case HERO_POSITION_JUMP_1:
    case HERO_POSITION_JUMP_8:
      upper = SPRITE_TERRAIN_EMPTY;
      lower = SPRITE_JUMP;
      break;
    case HERO_POSITION_JUMP_2:
    case HERO_POSITION_JUMP_7:
      upper = SPRITE_JUMP_UPPER;
      lower = SPRITE_JUMP_LOWER;
      break;
    case HERO_POSITION_JUMP_3:
    case HERO_POSITION_JUMP_4:
    case HERO_POSITION_JUMP_5:
    case HERO_POSITION_JUMP_6:
      upper = SPRITE_JUMP;
      lower = SPRITE_TERRAIN_EMPTY;
      break;
    case HERO_POSITION_RUN_UPPER_1:
      upper = SPRITE_RUN1;
      lower = SPRITE_TERRAIN_EMPTY;
      break;
    case HERO_POSITION_RUN_UPPER_2:
      upper = SPRITE_RUN2;
      lower = SPRITE_TERRAIN_EMPTY;
      break;
  }
  if (upper != ' ') {
    terrainUpper[HERO_HORIZONTAL_POSITION] = upper;
    collide = (upperSave == SPRITE_TERRAIN_EMPTY) ? false : true;
  }
  if (lower != ' ') {
    terrainLower[HERO_HORIZONTAL_POSITION] = lower;
    collide |= (lowerSave == SPRITE_TERRAIN_EMPTY) ? false : true;
  }

  byte digits = (score > 9999) ? 5 : (score > 999) ? 4 : (score > 99) ? 3 : (score > 9) ? 2 : 1;

  // Draw the scene
  terrainUpper[TERRAIN_WIDTH] = '\0';
  terrainLower[TERRAIN_WIDTH] = '\0';
  char temp = terrainUpper[16 - digits];
  terrainUpper[16 - digits] = '\0';
  lcd.setCursor(0, 0);
  lcd.print(terrainUpper);
  terrainUpper[16 - digits] = temp;
  lcd.setCursor(0, 1);
  lcd.print(terrainLower);

  lcd.setCursor(16 - digits, 0);
  lcd.print(score);

  terrainUpper[HERO_HORIZONTAL_POSITION] = upperSave;
  terrainLower[HERO_HORIZONTAL_POSITION] = lowerSave;
  return collide;
}

// Handle the button push as an interrupt

void buttonPush() {
  buttonPushed = true;
}

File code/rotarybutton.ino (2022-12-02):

/* ECE411 FALL2022 Team3
   Testing rotary encoder
   -Turning the knob clockwise will print out a statement that says "Rotating clockwise" 
   -Turning the knob counter-clockwise will print out a statement that says "Rotating counter-clockwise"
   -Pressing the button will print out a statement that says "Button pressed"
   
   -Read with 9600 baud rate on the serial monitor.

   Also need to implement a code that will read the rotations once - it currently senses each turn twice.
   Next, we should output the messages on the LCD display, then we can easily put in the timer,
   stopwatch, and game mode.

   For function returning to main menu, we can utilize 'if button pressed > 6 times, go to function'. This
   is equivalent to about 2 seconds. Would probably need to start a count everytime button is pressed
*/

//#include <LiquidCrystal_I2C.h>
//#include <Wire.h>

#define outputA 4 //output A = CLK = pin 4
#define outputB 3 //output B = DW = pin 3

//LiquidCrystal_I2C lcd(0x27,16,2);

//int counter = 0;
int aState;
int aLastState;
int pressButton = 2; //button = SW pin to Arduino pin 2

void setup() {
  //lcd.init(); //initialize LCD
  //lcd.backlight();  //turn on LCD backlight
  pinMode(outputA, INPUT);
  pinMode(outputB, INPUT);
  pinMode(pressButton, INPUT);

  Serial.begin(9600);
  aLastState = digitalRead(outputA); //reads initial state of outputA
}

void loop() {
  int buttonState = digitalRead(pressButton); //read input pin
  aState = digitalRead(outputA); //

  if(buttonState == 0) {
    Serial.print("Button pressed\n");
    delay(200);
  }

  //if the previous/current state of outputA are different, that means a pulse has occured
  if(aState != aLastState) {
    //if outputB state is different to outputA state, that means the encoder is rotating clockwise
    if(digitalRead(outputB) != aState) {
      //counter++;
      Serial.print("Rotating clockwise\n");
    }
    else {
      //counter--;
      Serial.print("Rotating counter-clockwise\n");
    }
    //Serial.print("Position: ");
    //Serial.println(counter);
  }
  aLastState = aState;  //update the previous state of outputA with current state
  //we don't want to add a delay for the rotation of the knobs - it makes us wait a lil before we can turn again
}

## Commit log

2022-10-27 Week 5: Preliminary Schematic
2022-10-27 Week 5: Preliminary Schematic (updatedx1)
2022-11-03 Week 6: Draft of KiCad schematic
2022-11-03 new folder for schematics
2022-11-03 kicad schematic file
    [11-3_Schematic.kicad_sch]
2022-11-04 corrected gnd wire on right side
    [11-3_Schematic.kicad_sch]
2022-11-04 corrected wire going to gnd on right side
    [11-3_Schematic.kicad_sch]
2022-11-10 almost complete
    [ECE411_KiCadSchematic.kicad_sch, ECE411_PCBLayout.kicad_pcb]
2022-11-10 update extra line across power switch
    [ECE411_KiCadSchematic.kicad_sch]
2022-11-10 BOM excel and pdf
    [ECE411_BOM.xlsx]
2022-11-15 updated pcb and circuit schematic
    [ECE411_KiCadSchematic.kicad_sch, ECE411_PCBLayout.kicad_pcb]
2022-11-17 final CAD
    [ECE411_PCBLayout.kicad_pcb]
2022-12-02 rotary encoder tester
2022-12-08 updated docs
    [ECE411_BOM.xlsx]
2022-12-08 fixed name typo
    [ECE411_PCBLayout.kicad_pcb]
